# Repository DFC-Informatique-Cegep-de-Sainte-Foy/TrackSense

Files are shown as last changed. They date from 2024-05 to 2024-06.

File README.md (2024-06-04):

# TrackSense 

> Le projet TrackSense est développé par des étudiants du programme [Techniques de l'informatique - Programmation, bases de données et serveurs - DEC accéléré](https://dfc.csfoy.ca/retourner-aux-etudes/programmes-a-temps-plein/informatique/techniques-de-linformatique-programmation-bases-de-donnees-et-serveurs-dec-accelere/) du cégep de Ste-Foy, dans le cadre de leur projet de synthèse.

<p align="center">
    Logo_TrackSense
</p>

> - TrackSense est un boitier à fixer sur votre vélo pour enregistrer vos trajets.
> - L'application mobile permet la récupération, l'affichage et la sauvegarde des trajets. Elle sert également à la configuration du TrackSense.
> - L'API (serveur Web) est l'interface permettant de sauvegarder et récupérer les trajets.
> - La base de données sert à sauvegarder les données.
<p align="center">
    Logo_TrackSense
</p>

> Le présent dépôt rassemble les informations générales et tout ce qui n'est pas du développement des applications (embarquée, mobile, Web, Base de données). Chaque application à son dépôt.

## Créer votre TrackSense !

> Pour garantir le bon fonctionnement de votre TrackSense, de sa communication avec votre application mobile et la sauvegarde de vos données, veuillez suivre les étapes [disponibles ici](https://github.com/DFC-Informatique-Cegep-de-Sainte-Foy/TrackSense/wiki) !

<p align="center">
    Logo_TrackSense
</p>

## Application embarquée

> L'application embarquée est le programme qui va s'exécuter à l'intérieur de votre TrackSense.
> Vous trouverez son dépôt GitHub [ici](https://github.com/DFC-Informatique-Cegep-de-Sainte-Foy/420-W57-SF_TrackSense_AppEmbarque).

<p align="center">
    Logo_TrackSense
</p>

## Application mobile

> L'application mobile est nécessaire pour configurer et communiquer avec votre TrackSense.
> Vous trouverez son dépôt GitHub [ici](https://github.com/DFC-Informatique-Cegep-de-Sainte-Foy/420-W57-SF_TrackSense_AppMobile).

<p align="center">
    Logo_TrackSense
</p>

## Application Web (API)

> L'application Web est l'interface qui vous permet de communiquer avec votre base de données. Elle peut être hébergée en ligne ou chez vous.
> Vous trouverez son dépôt GitHub [ici](https://github.com/DFC-Informatique-Cegep-de-Sainte-Foy/420-W57-SF_TrackSense_ServeurWeb).

## Base de données

> La base de données est l'endroit où sont stockées vos données. Elle n'est accessible que via l'application Web.
> Vous trouverez son dépôt GitHub [ici](https://github.com/DFC-Informatique-Cegep-de-Sainte-Foy/420-W57-SF_TrackSense_BD).

## Manuel utilisateur

> Comment utiliser mon TrackSense ? Quelles sont les fonctionnalités ? Ça fait quoi quand j'appuie sur un bouton ?
> Pour avoir toutes les réponses à ces questions et bien d'autres, vous trouverez le manuel de l'utilisateur [ici](https://github.com/DFC-Informatique-Cegep-de-Sainte-Foy/TrackSense/wiki/Manuel) !  

## Informations générales

<p align="center">
    Logo_TrackSense
</p>

> Quelques informations et/ou éléments supplémentaires :
> - [Logo](./TrackSense/tree/main/Logo/)
> - [Composants](./TrackSense/tree/main/Composants)

## Contributeurs

### Session hiver 2024

>-  [David Fournel-Vézina](https://github.com/DavidFV2296190)
>-  [Rémi St-Pierre](https://github.com/ray3331)
>-  [Changfeng Zhao](https://github.com/Kuma-Lingxi)

### Session été 2023

>-  [Dominique Lebrun](https://github.com/dodo-12-37)
>-  [Loïc Delas](https://github.com/LoicDelas)
>-  [Tien Binh Nguyen](https://github.com/binhnguyen84)
>-  [Simon Quillaud](https://github.com/simonquillaud)

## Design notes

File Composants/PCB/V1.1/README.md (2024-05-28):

# Tracksense PCB V1.1
## Design
Cette nouvelle plaquette est compatible avec le LilyGo T-SIM7600x. Tous les fichiers produits avec [KiCad V8.0.0](https://gitlab.com/kicad) sont placés sous le répertoire KiCad. Il est possible de faire fabriquer cette plaquette chez de multiples fournisseurs. Pour simplifier le processus de fabrication de la plaquette, le répertoire [*Kicad/TrackSense-T-SIM7600x/Production*](\KiCad\TrackSense_T-SIM7600x\production) contient une archive ZIP qui peut être directement téléversé sur le site de [JLCPCB](https://jlcpcb.com). Cette archive a été construite à l'aide de l'extension KiCad [Fabrication Toolkit](https://github.com/bennymeg/Fabrication-Toolkit) qui permet de produire les fichiers Gerber ainsi qu'une nomenclature (*bill of materials*). Il est donc ainsi possible de faire assembler la plaquette et d'y faire installer le connecteurs par le fabricant. (*Toutes les composantes peuvent être facilement soudées à la main pour réduire les coûts*)

### Vue du dessus
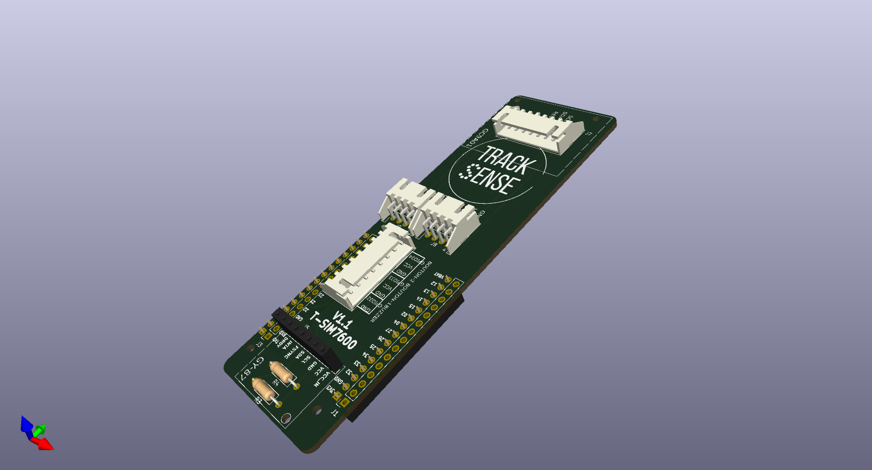
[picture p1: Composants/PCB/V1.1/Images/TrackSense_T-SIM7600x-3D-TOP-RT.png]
Vue du dessus

### Vue du dessous
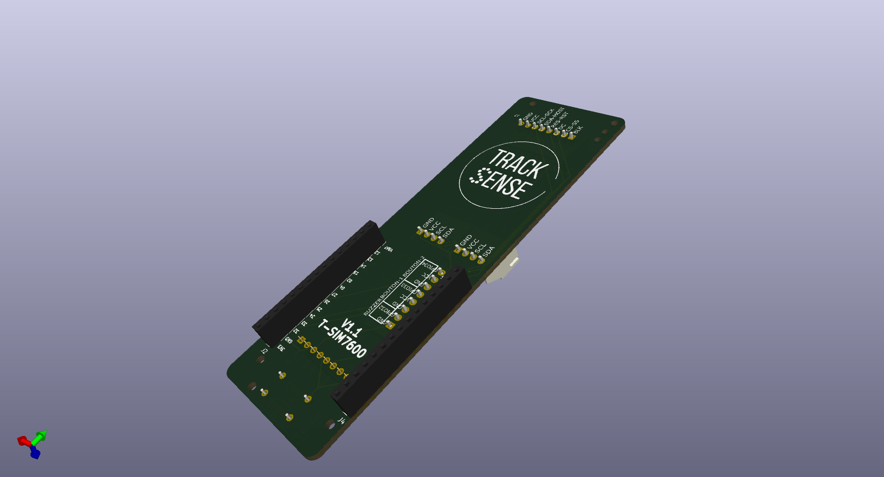
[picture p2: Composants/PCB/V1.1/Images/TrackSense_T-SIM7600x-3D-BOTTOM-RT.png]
Vue du dessous


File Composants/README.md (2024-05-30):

# Composants

> Vous trouverez-ici l'ensemble des détails concernant les composants du TrackSense.

## Composants électroniques

## Boitier et visserie

> Le boitier actuel est à la version 1.0. Il a été conçu pour être imprimé en 3D. 
> Le boitier (couvercle, socle et btognau) à un poids d'environ 75g.
> Les plans sont disponibles aux formats suivants :
>   - dwg
>   - dxf
>   - f3d
>   - step

> L'ensemble de la visserie utilise du [filetage métrique M2](https://fr.wikipedia.org/wiki/Filetage_m%C3%A9trique#Pas_standard)
> - Quatre (4) tiges filetées : 
>    - &Oslash; : M2
>    - Longueur : 50 mm
> - Six (6) inserts filetés thermiques pour plastique :
>    - &Oslash; intérieur : M2
>    - &Oslash; extérieur : 3.5 mm
>    - Hauteur : 3 mm
> - Six (6) écrous de blocage :
>    - &Oslash; : M2
> - Deux (2) vis :
>    - &Oslash; : M2
>    - Longueur : 4 mm

## Estimation des coûts (2024)

> Voici des exemples de liens (non mis à jour) pour l'achat des composants ainsi qu'un prix **aproximatif** en dollar canadien.

| **Nom** | **Lien** | **Prix** |
| --- | --- | --- |
| Lilygo T-SIM7600G 16MB | [Lilygo T-SIM7600G-H R2 V1.2](https://www.lilygo.cc/products/t-sim7600?variant=42774480224437) | 58.50$ US |
| Écran GC9A01 | [aliexpress](https://www.aliexpress.us/item/3256803883388742.html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) | 4.00$ |
| Accéléromètre GY-87 | [aliexpress](https://www.aliexpress.us/item/2255800048225074.html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) | 4.00$ |
| Buzzer SFM-27 | [aliexpress](https://www.aliexpress.us/item/3256801606373820.html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) | 1.00$ |
| [PCB (x5)](./PCB/V1.1/README.md)| [JLCPCB](https://jlcpcb.com/) | 10$ |
| Connecteurs JST 4 pins (mâle et femelle) | [aliexpress](https://fr.aliexpress.com/item/4000120545240.html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) | 1.80$ |
| Connecteurs JST 8 pins (mâle et femelle) | [aliexpress](https://fr.aliexpress.com/item/4000120545240.html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) | 3.60$ |
| Connecteurs femelle 16 pins | [aliexpress](https://fr.aliexpress.com/item/1005003406780797.html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) | 1.50$ |
| Vis M2 | [aliexpress](https://fr.aliexpress.com/item/1005003083573172.html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) | 1.50$ |
| Écrous autobloquant M2 | [aliexpress](https://fr.aliexpress.com/item/4000075372035.html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) | 4.00$ |
| Inserts filetés M2 | [aliexpress](https://fr.aliexpress.com/item/1005003452792764.html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) | 5.00$ |
| Tiges fileteés M1 | [aliexpress](https://fr.aliexpress.com/item/1005001578222754.html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) | 7.00$ |
| Filament imprmante 3D | [aliexpress](https://fr.aliexpress.com/item/1005005581829928.html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) | 26.00$ |

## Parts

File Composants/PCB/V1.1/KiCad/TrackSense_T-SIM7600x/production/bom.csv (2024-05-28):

Designator | Footprint | Quantity | Value | LCSC Part #
Hole_gge12314 | Hole_gge12314 | 1 | Hole_gge12314
Hole_gge26318 | Hole_gge26318 | 1 | Hole_gge26318
Hole_gge26333 | Hole_gge26333 | 1 | Hole_gge26333
Hole_gge31514 | Hole_gge31514 | 1 | Hole_gge31514
Hole_gge31529 | Hole_gge31529 | 1 | Hole_gge31529
Hole_gge6255 | Hole_gge6255 | 1 | Hole_gge6255
Hole_gge6258 | Hole_gge6258 | 1 | Hole_gge6258
J1, J2, J3, J4 | PinSocket_1x15_P2.54mm_Vertical | 4 | Conn_01x15_Socket
J5 | PinSocket_1x08_P2.54mm_Vertical | 1 | Conn_01x08_Socket
J6, J7 | JST_XH_S8B-XH-A-1_1x08_P2.50mm_Horizontal | 2 | Conn_01x08_Pin
J8, J9 | JST_XH_S4B-XH-A_1x04_P2.50mm_Horizontal | 2 | Conn_01x04_Pin
R3, R4 | R_Axial_DIN0207_L6.3mm_D2.5mm_P10.16mm_Horizontal | 2 | 4.7k

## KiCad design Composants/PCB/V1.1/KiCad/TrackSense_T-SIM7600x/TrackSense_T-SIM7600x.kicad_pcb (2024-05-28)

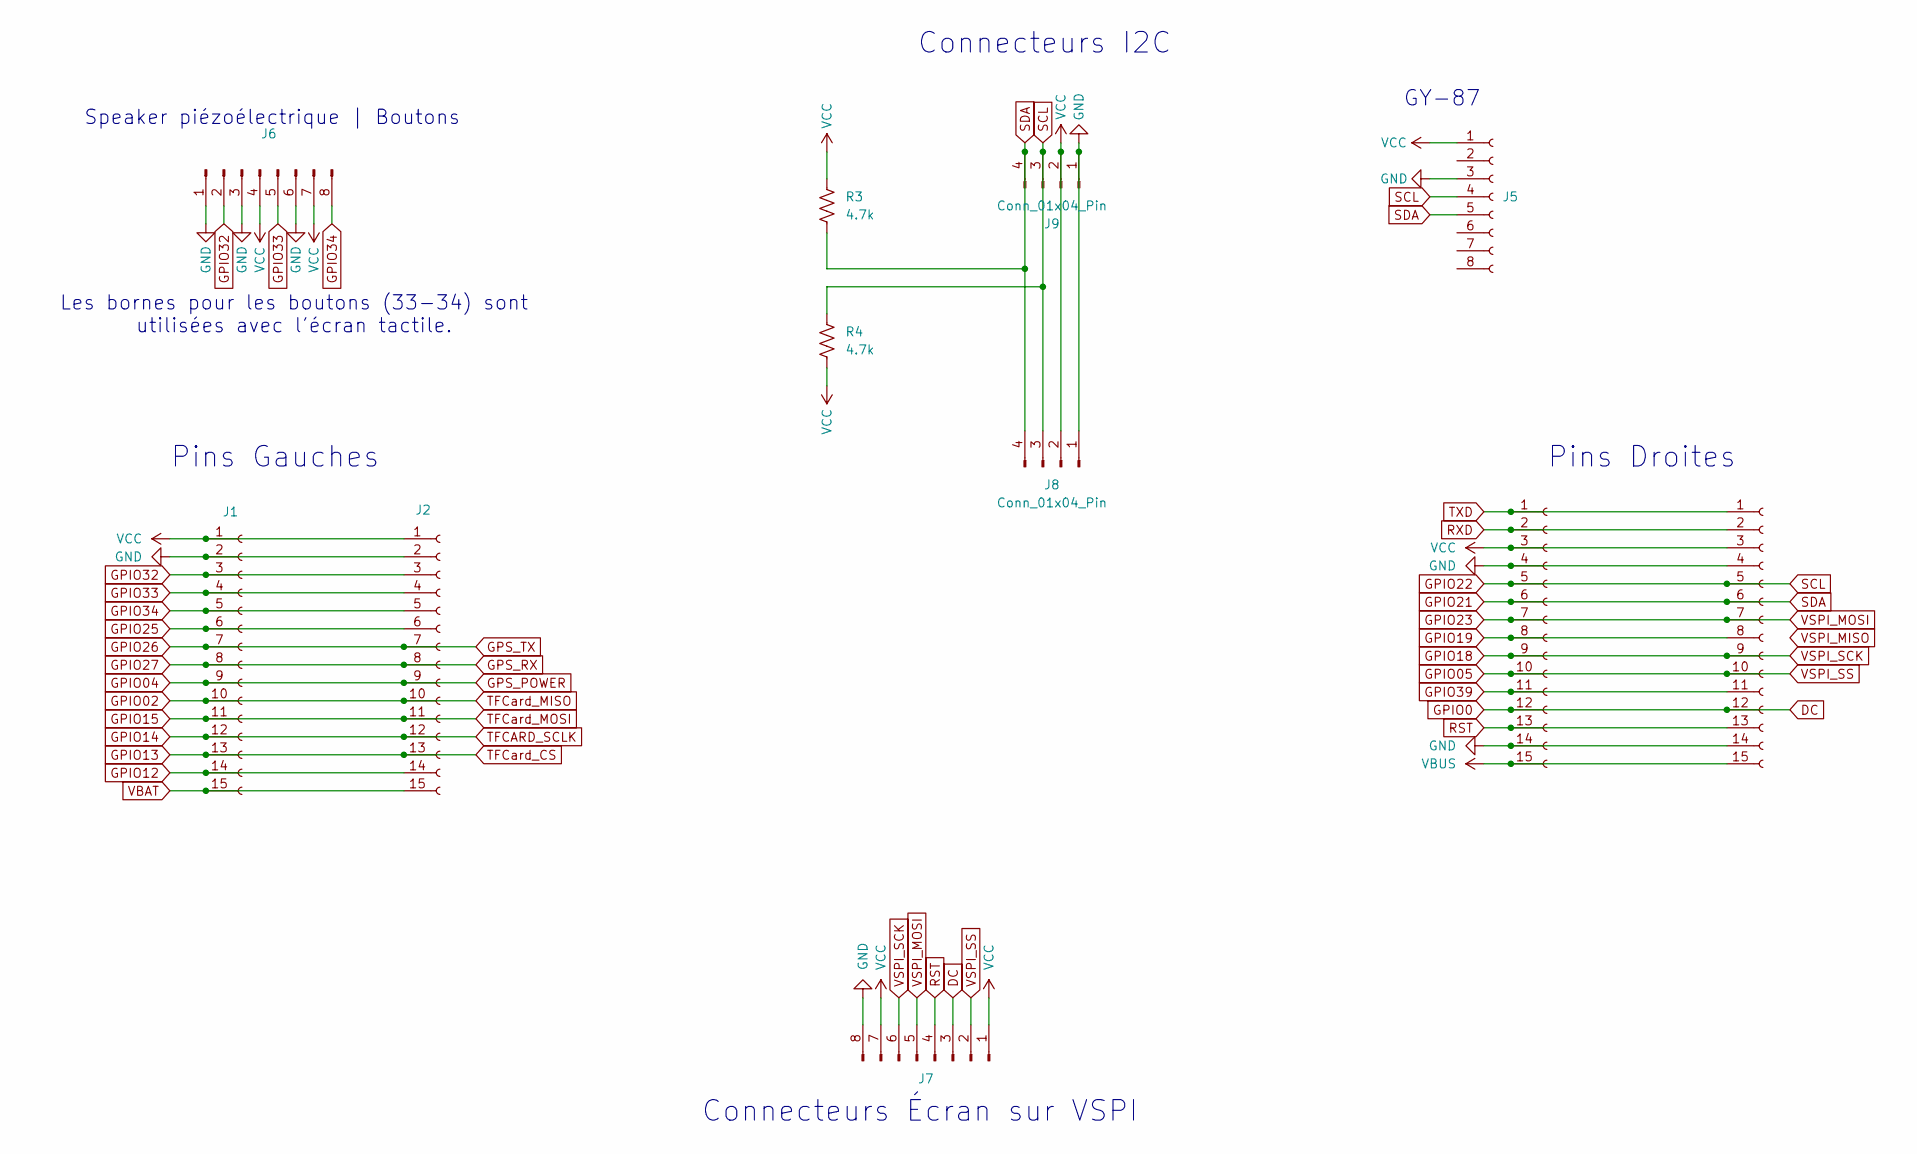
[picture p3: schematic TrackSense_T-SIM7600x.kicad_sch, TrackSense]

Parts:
J1, J2, J3, J4: Conn_01x15_Socket; PinSocket_1x15_P2.54mm_Vertical
J5: Conn_01x08_Socket; PinSocket_1x08_P2.54mm_Vertical
J6, J7: Conn_01x08_Pin; JST_XH_S8B-XH-A-1_1x08_P2.50mm_Horizontal
J8, J9: Conn_01x04_Pin; JST_XH_S4B-XH-A-1_1x04_P2.50mm_Horizontal
R3, R4: 4.7k; R_Axial_DIN0207_L6.3mm_D2.5mm_P10.16mm_Horizontal

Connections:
DC: J3.12, J4.12, J7.3
GND: J1.2, J2.2, J3.4, J3.14, J4.4, J4.14, J5.3, J6.1, J6.3, J6.6, J7.8, J8.1, J9.1
GPIO02: J1.10, J2.10
GPIO04: J1.9, J2.9
GPIO05: J3.10, J4.10, J7.2
GPIO12: J1.14, J2.14
GPIO13: J1.13, J2.13
GPIO14: J1.12, J2.12
GPIO15: J1.11, J2.11
GPIO18: J3.9, J4.9, J7.6
GPIO19: J3.8, J4.8
GPIO21: J3.6, J4.6, J5.5, J8.4, J9.4, R3.2
GPIO22: J3.5, J4.5, J5.4, J8.3, J9.3, R4.2
GPIO23: J3.7, J4.7, J7.5
GPIO25: J1.6, J2.6
GPIO26: J1.7, J2.7
GPIO27: J1.8, J2.8
GPIO32: J1.3, J2.3, J6.2
GPIO33: J1.4, J2.4, J6.5
GPIO34: J1.5, J2.5, J6.8
GPIO39: J3.11, J4.11
RST: J3.13, J4.13, J7.4
RXD: J3.2, J4.2
TXD: J3.1, J4.1
VBAT: J1.15, J2.15
VBUS: J3.15, J4.15
VCC: J1.1, J2.1, J3.3, J4.3, J5.1, J6.4, J6.7, J7.1, J7.7, J8.2, J9.2, R3.1, R4.1

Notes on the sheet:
Pins Droites
Connecteurs I2C
Les bornes pour les boutons (33-34) sont utilisées avec l'écran tactile.
GY-87
Pins Gauches
Connecteurs Écran sur VSPI
Speaker piézoélectrique | Boutons

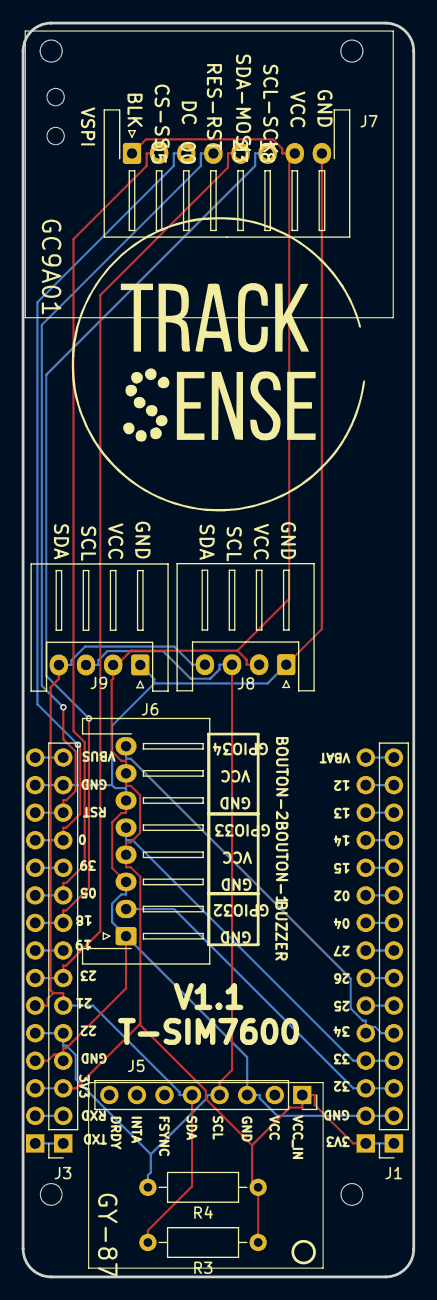
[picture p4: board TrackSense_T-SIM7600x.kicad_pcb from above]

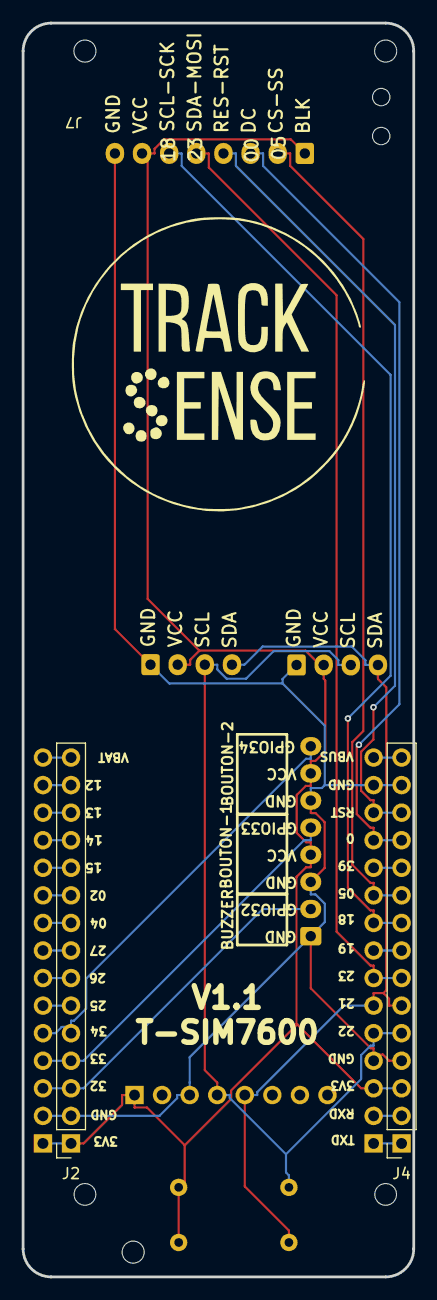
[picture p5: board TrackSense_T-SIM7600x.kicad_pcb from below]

Board: 2 copper layers, 36.0 x 115.5 mm, 20 parts (3 on the bottom side), 27 nets.

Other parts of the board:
G1, G2: LOGO; TS_LOGO_FOOTPRINT
Hole_gge6255: Hole_gge6255
Hole_gge6258: Hole_gge6258
Hole_gge12314: Hole_gge12314
Hole_gge26318: Hole_gge26318
Hole_gge26333: Hole_gge26333
Hole_gge31514: Hole_gge31514
Hole_gge31529: Hole_gge31529
